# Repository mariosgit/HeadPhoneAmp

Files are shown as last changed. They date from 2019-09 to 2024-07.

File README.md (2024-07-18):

# HeadPhoneAmp

New plan... Make my own HP Amp.

##### Requirements:

* EQ - I dont have many HP's which I don't want to EQ, they all need a little something.
* Lipo Powered !
* Line In

##### Goodies

* More Inputs (in that order)
   * USB (Teensy4 can also control DSP, Bluetooth, 16bit is ok for playback)
   * BT (just plug in a module CSR8635?)
   * WLAN (Radio, Subsonic and Ampache protocols for nextcloud music) cry for ESP32 (rabbithole! [bt a2dp](https://github.com/pschatzmann/ESP32-A2DP) [iradio](https://github.com/Edzelf/ESP32Radio-V2) [streem gedoehns](https://github.com/sle118/squeezelite-esp32) )
   * SPDIF (not really on a HP amp)
* Second output ? With it's own EQ and Volume ?
* NuTube or Simulation of a little distortion. Maybe other effects ?
* MP3 player - there is one for the teensy. Would need SDCard or so, How to copy files ? Just swap the card ? The Cardhold would obscure the VUSB hack !
* ~~Radio streaming.. WLAN hasl...~~

# Status

* Theory is somewhat more defined in my head.
* Started to build some blocks
    * TPA6120 module - Made my own, running with only single 5V - to be tested.
    * DSP - I have a freeDSP-SMD-B to experiment with
    * NuTube ? I have a NuTube HP Amp which is'nt great but could be recycled into something usefull - not so available !

# Next up ?

#### HPAmp design ?

* TPA6120A2 in the works with 5V conveter, it's big (there is a QFN version)

#### Power Block Design

* Use Adafruit PowerThing ?
    * Added charge pump for 10V as in the DS
* How to get the teensy integrated, would need to patch into VUSB -> PowerBlock -> 5V back to the Teensy ?
    * Cut trace in the back, solder some wire to VUSB ? Or use pogopins ? Not nice.
* Noise ??? Will see... yes 200mVpp @ 65kHz, audible when directly driving a 16ohm speaker

* Cap Mult for analog voltage, or just a regulator ? [SIM](https://www.falstad.com/circuit/circuitjs.html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)

##### Results v0.1

* C6 can be much larger according to DS. Available up to 220uF.
* Has no BAT protection ? The testbat emptied down to 2V ! Just clarify.
* Make charge Amps quick changeable with a PHT resistor ?
* Could add a PG PowerGood LED, this shows when device is connected to some power source
* Check 10V load ❗
* Add option for higher voltage as in the GP??94 controller ?

##### Bugs v0.1

* ! Q1 is **wrong** MMUN2133LT1G it's BEC(123) - just switched to the "BEC" symbol. ✅
* C5 (+10V) was connected to ground, should be between +10 and +5V, works anyway ✅

#### NuTube

* Create own board 
    * Bias voltage driven by OpAmp ! Input a single Pot or CV
    * With ADC ? as a FX loopback ?

#### VFD/OLED

* Make board for MN12832 ?
    * Can I borrow voltage from the booster ? Add more charge pumps..

#### Teensy + DSP

* Can the teensy be slave i2s ??? Otherwise it would need an extra SRC.
    There is a slave i2s out... Will it work with usb, does it need to be 44100kHz ?
    ```
    AudioInputUSB            usb1;
    AudioOutputI2Sslave      i2sslave1;
    AudioConnection          patchCord1(usb1, 0, i2sslave1, 0);
    AudioConnection          patchCord2(usb1, 1, i2sslave1, 1);
    ```
    ```File > Examples > Audio > HardwareTesting > WM8731MikroSine```
    *Notes: Slave mode I2S should not used in the same project as ADC, DAC and PWM signals. Differences in timing between the I2S device and Teensy's clock can cause occasional audio glitches when I2S slave mode is used together with other input or output objects based on Teensy's timing. ...Only one I2S input and one I2S output object may be used. Master and slave modes may not be mixed (both must be of the same type).*
    Mhm wanted to use the internal DAC for NuTube bias...
* Test I2S slave (with DSP)
* Test internal DAC for NuTube

#### BT Audio

* Ahh just another SRC needed ??? Or switch them between Teensy and BT ? And SPDif ?
* Make a SPDIF/BT/USB I2S Switch + SRC  block design. it's all there.

##### Advanced 

* Loop back Nutube ? With an extra ADC or CODEC ? Ad

# Log

| What | Time | Cost || What | Time | Cost |
|---|---|---|---|---|---|---|
| Make Power PCB | 1d | | | Test,Fix Power PCB | 1d | |
|  Make HPBooster PCB | 1d | | | | | |
| both mat+pcb | | 50 + 30 | | |

# Refs

Used some Symbols... https://github.com/wykys/klib 

Ti's [I2C expander collection](https://www.ti.com/interface/i2c/general-purpose-ios-gpios/overview.html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)

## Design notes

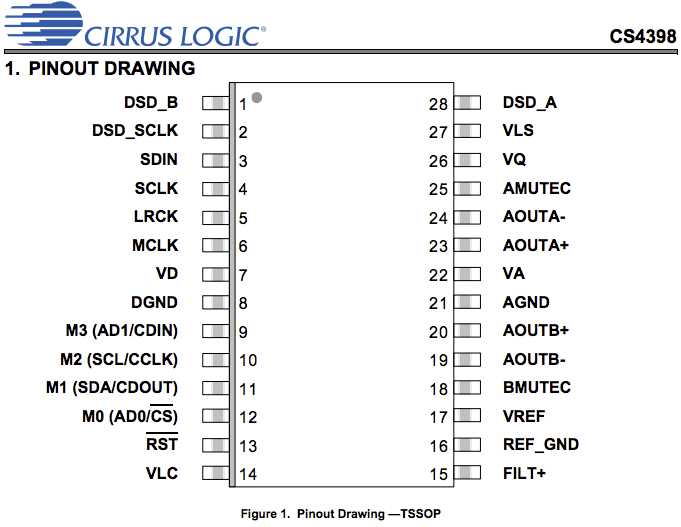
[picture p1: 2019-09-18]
images/CS4398pinout.png

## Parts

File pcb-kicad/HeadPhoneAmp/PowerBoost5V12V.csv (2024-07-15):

Reference | Value | Footprint | Qty | # | MFNAME
B1,CHRG/LBO0,DONE0,JP2,LED1,LED2,TP1,TP2,TP3,TP4,TP5 | ~ | -- mixed values -- | 11 | 1
C1,C2,C5,C7,C8 | 2.2u | Capacitor_SMD:C_0603_1608Metric_Pad1.08x0.95mm_HandSolder | 5 | 2 | EMK107BJ225KA-T
C3,C4 | 100n | Capacitor_SMD:C_0603_1608Metric_Pad1.08x0.95mm_HandSolder | 2 | 3 | C0603C104M4RAC7411
C6 | 22u | Capacitor_SMD:C_1210_3225Metric_Pad1.33x2.70mm_HandSolder | 1 | 4 | 293D226X96R3A2TE3
D1 | BAT54S | Package_TO_SOT_SMD:SOT-23 | 1 | 5 | BAT54S
L1 | 6.8uH 2A | Adafruit PowerBoost 1000C Rev B:INDUCTOR_5X5MM_TDK_VLC5045 | 1 | 6 | 74406042068
Q1 | Q_PNP_ECB_BRT | Package_TO_SOT_SMD:SOT-23 | 1 | 7 | MMUN2133LT1G
R1,R3 | 1.87M | Resistor_SMD:R_0603_1608Metric_Pad0.98x0.95mm_HandSolder | 2 | 8 | RK73H1HTTCM4302D RK73H1JTTD1874F
R2 | 340k | Resistor_SMD:R_0603_1608Metric_Pad0.98x0.95mm_HandSolder | 1 | 9 | RK73H1JTTD3403F
R4,R7,R9,R13,R17 | 100k | Resistor_SMD:R_0603_1608Metric_Pad0.98x0.95mm_HandSolder | 5 | 10 | RK73H1JTTD1003F
R5,R8,R14,R16,R20 | 1k | Resistor_SMD:R_0603_1608Metric_Pad0.98x0.95mm_HandSolder | 5 | 11 | RK73H1JTTD1001F
R6 | 270k | Resistor_SMD:R_0603_1608Metric_Pad0.98x0.95mm_HandSolder | 1 | 12 | RK73H1JTTD2703F
THERM0 | 15k | Resistor_SMD:R_0603_1608Metric_Pad0.98x0.95mm_HandSolder | 1 | 13 | RK73H1JTTD1502F
U1 | VREG_TPS6103X | HPAmp:PVQFN-16 | 1 | 14 | TPS61090RSAR
U2 | MCP73871 | HPAmp:QFN20_4MM | 1 | 15 | MCP73871T

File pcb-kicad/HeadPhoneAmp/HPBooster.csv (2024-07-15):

Reference | Value | Qty | MFNAME
C1,C4,C5,C6,C7 | 10u | 5 | -
C2,C3,C8,C9,C42,C43 | 100n | 6 | -
FB1,FB2,FB3 | FerriteBead | 3 | -
J1,J2,J3,TP1,TP2,TP3,TP5+1,TP5-1 | ~ | 8 | -
L1 | 2.2uH | 1 | CC453232-2R2KL
R1 | 365k | 1 | RK73H1JTTD3653F
R2,R3 | 47 | 2 | RK73H1JTTD47R0F
R4,R5 | 39.2 | 2 | RK73H3ATTE39R2F
R6 | 120k | 1 | RK73H1JTTD1203F
R7 | 487k | 1 | RK73H1JTTD4873F
R36,R37,R38,R39 | 1k | 4 | -
U1 | TPS65135 | 1 | -
U5 | TPA6120A2RGY | 1 | -

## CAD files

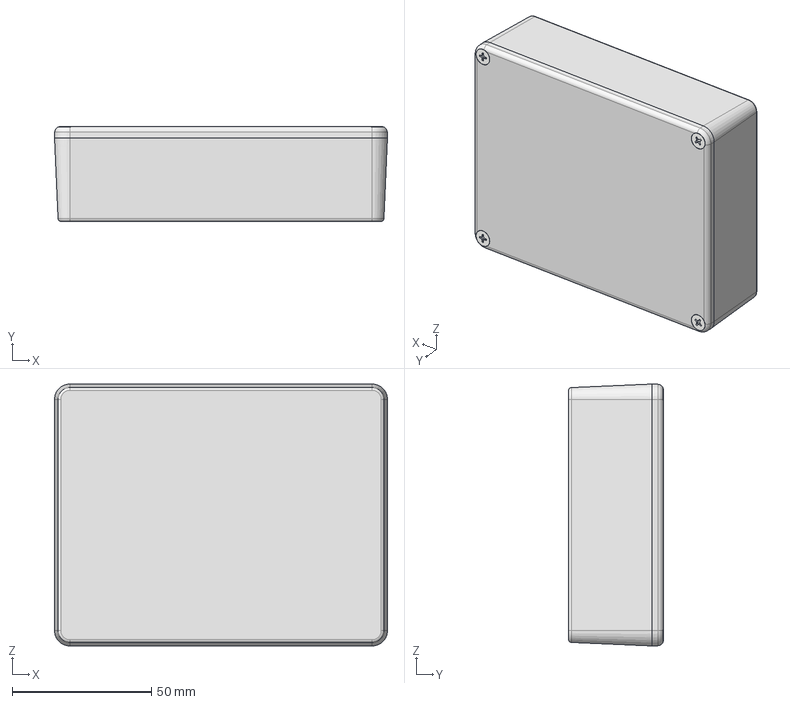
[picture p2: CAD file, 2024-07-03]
pcb-kicad/3dModels/Case1590BB.stp
119.5 x 34.0 x 94.0 mm

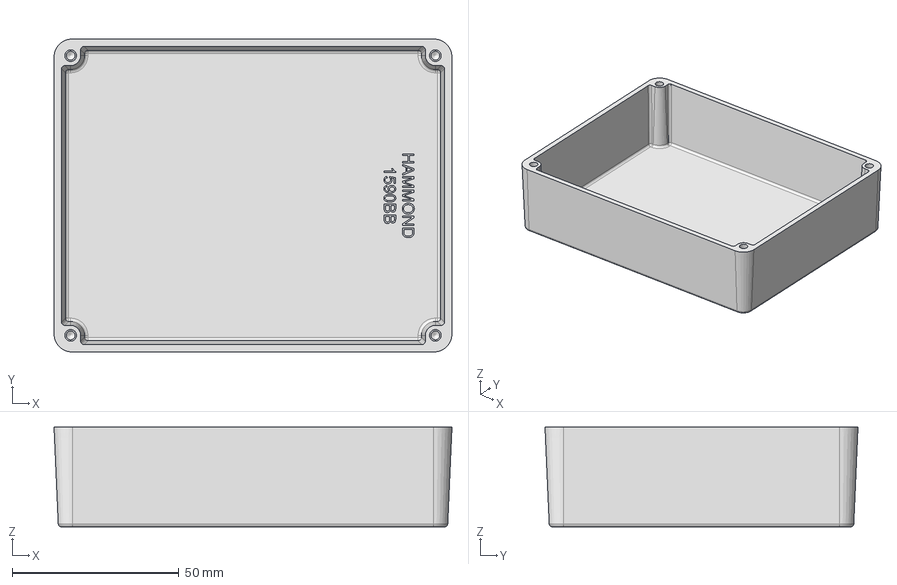
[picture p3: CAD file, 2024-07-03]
pcb-kicad/3dModels/Case1590BB-TOP.step
119.5 x 94.0 x 30.0 mm

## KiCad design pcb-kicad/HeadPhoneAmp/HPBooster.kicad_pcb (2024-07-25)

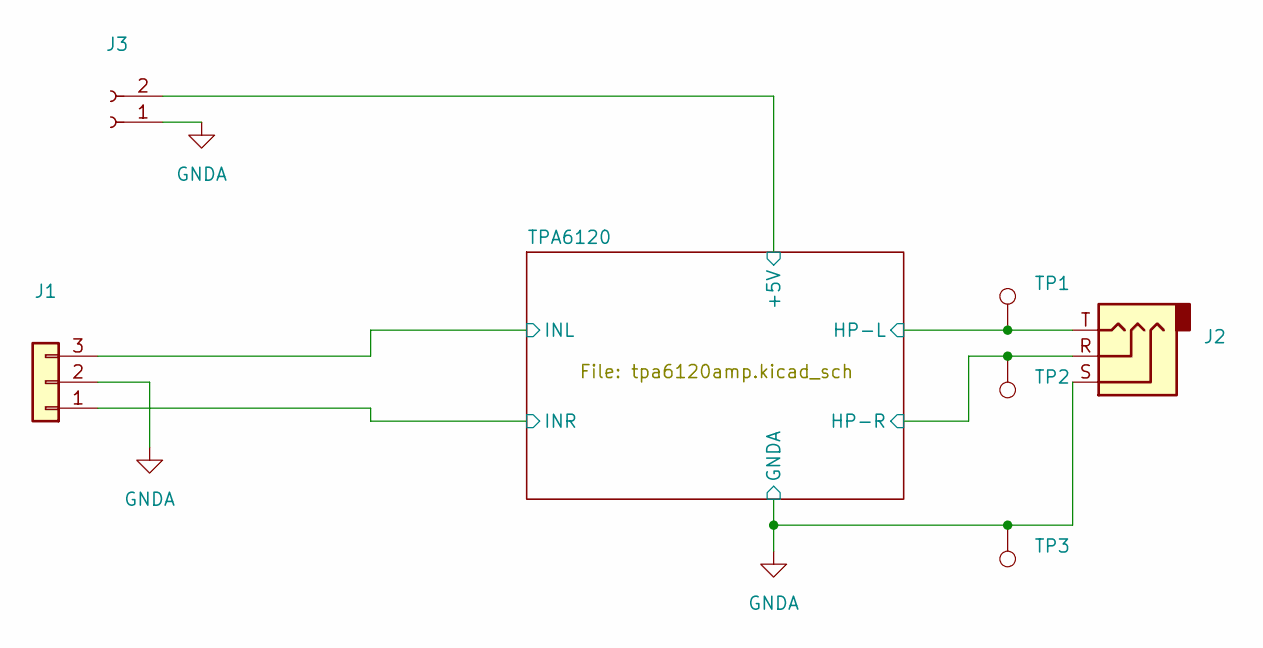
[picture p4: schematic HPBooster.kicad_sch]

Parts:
J1: JST_EH_B3B-EH-A_1x03_P2.50mm_Vertical
J2: Jack_3.5mm_CUI_SJ-3523-SMT_Horizontal
J3: PinHeader_1x02_P2.54mm_Vertical
TP1, TP2, TP3: TestPoint_Loop_D1.80mm_Drill1.0mm_Beaded

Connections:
+5V: J3.2; also elsewhere on the board
/TPA6120/HP-L: J2.T, TP1.1; also elsewhere on the board
/TPA6120/HP-R: J2.R, TP2.1; also elsewhere on the board
/TPA6120/INL: J1.3; also elsewhere on the board
/TPA6120/INR: J1.1; also elsewhere on the board
GNDA: J1.2, J2.S, J3.1, TP3.1; also elsewhere on the board

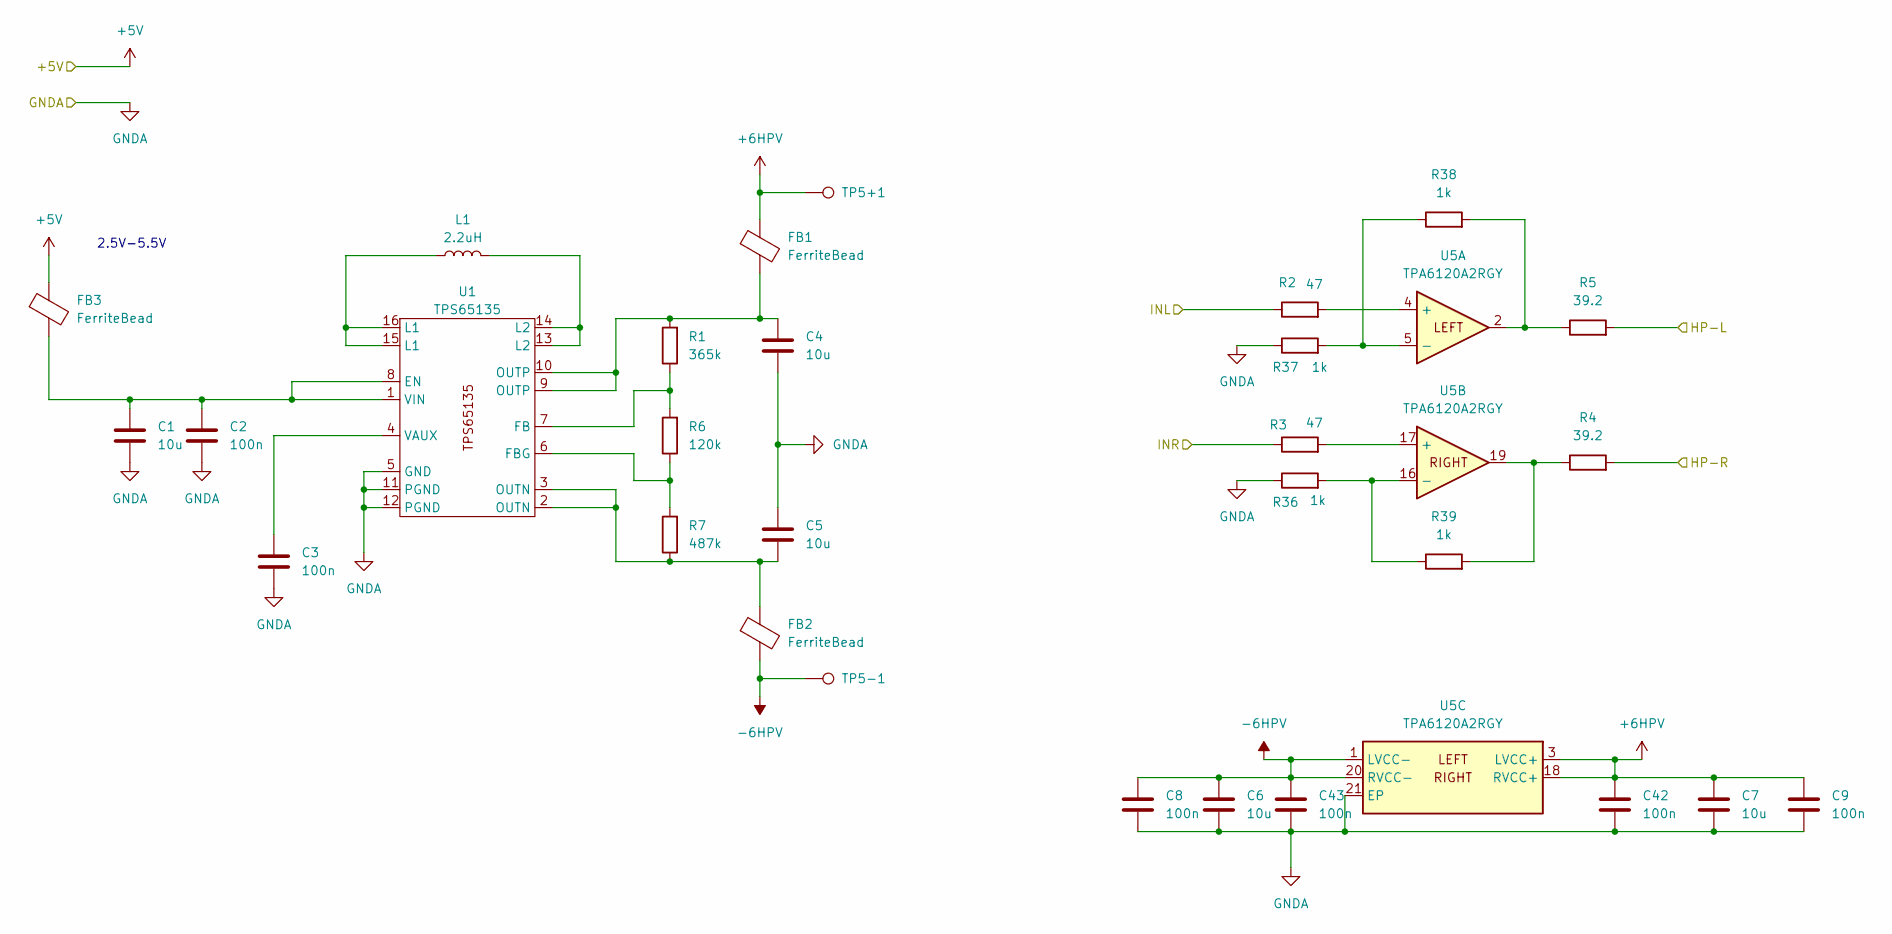
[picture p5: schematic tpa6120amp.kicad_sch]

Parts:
C1, C4, C5, C6, C7: 10u; C_0603_1608Metric_Pad1.08x0.95mm_HandSolder
C2, C3, C8, C9, C42, C43: 100n; C_0603_1608Metric_Pad1.08x0.95mm_HandSolder
FB1, FB2, FB3: FerriteBead; L_0603_1608Metric_Pad1.05x0.95mm_HandSolder
L1: 2.2uH; L_1812_4532Metric_Pad1.30x3.40mm_HandSolder
R1: 365k; R_0603_1608Metric_Pad0.98x0.95mm_HandSolder
R2, R3: 47; R_0603_1608Metric_Pad0.98x0.95mm_HandSolder
R4, R5: 39.2; R_2512_6332Metric_Pad1.40x3.35mm_HandSolder
R6: 120k; R_0603_1608Metric_Pad0.98x0.95mm_HandSolder
R7: 487k; R_0603_1608Metric_Pad0.98x0.95mm_HandSolder
R36, R37, R38, R39: 1k; R_0603_1608Metric_Pad0.98x0.95mm_HandSolder
TP5+1, TP5-1: TestPoint_Pad_2.0x2.0mm
U1: TPS65135; WQFN-16-1EP_3x3mm_P0.5mm_LongPad_ThermalVia
U5: TPA6120A2RGY; SOP-20_7.5x12.8mm_P1.27mm

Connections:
+5V: FB3.1; also elsewhere on the board
+6HPV: C7.1, C9.1, C42.1, FB1.1, TP5+1.1, U5.3 (LVCC+), U5.18 (RVCC+)
-6HPV: C6.1, C8.1, C43.1, FB2.2, TP5-1.1, U5.1 (LVCC-), U5.20 (RVCC-)
/TPA6120/HP-L: R5.2; also elsewhere on the board
/TPA6120/HP-R: R4.2; also elsewhere on the board
/TPA6120/INL: R2.1; also elsewhere on the board
/TPA6120/INR: R3.1; also elsewhere on the board
GNDA: C1.2, C2.2, C3.2, C4.2, C5.1, C6.2, C7.2, C8.2, C9.2, C42.2, C43.2, R36.1, R37.1, U1.5 (GND), U1.11 (PGND), U1.12 (PGND), U5.21 (EP); also elsewhere on the board
unnamed: C4.1, FB1.2, R1.2, U1.9 (OUTP), U1.10 (OUTP)
unnamed: C5.2, FB2.1, R7.1, U1.2 (OUTN), U1.3 (OUTN)
unnamed: L1.1, U1.15 (L1), U1.16 (L1)
unnamed: L1.2, U1.13 (L2), U1.14 (L2)
unnamed: R5.1, R38.2, U5.2
unnamed: R4.1, R39.2, U5.19
unnamed: C1.1, C2.1, FB3.2, U1.1 (VIN), U1.8 (EN)
unnamed: R1.1, R6.2, U1.7 (FB)
unnamed: R6.1, R7.2, U1.6 (FBG)
unnamed: C3.1, U1.4 (VAUX)
unnamed: R2.2, U5.4 (+)
unnamed: R37.2, R38.1, U5.5 (-)
unnamed: R3.2, U5.17 (+)
unnamed: R36.2, R39.1, U5.16 (-)

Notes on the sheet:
2.5V-5.5V

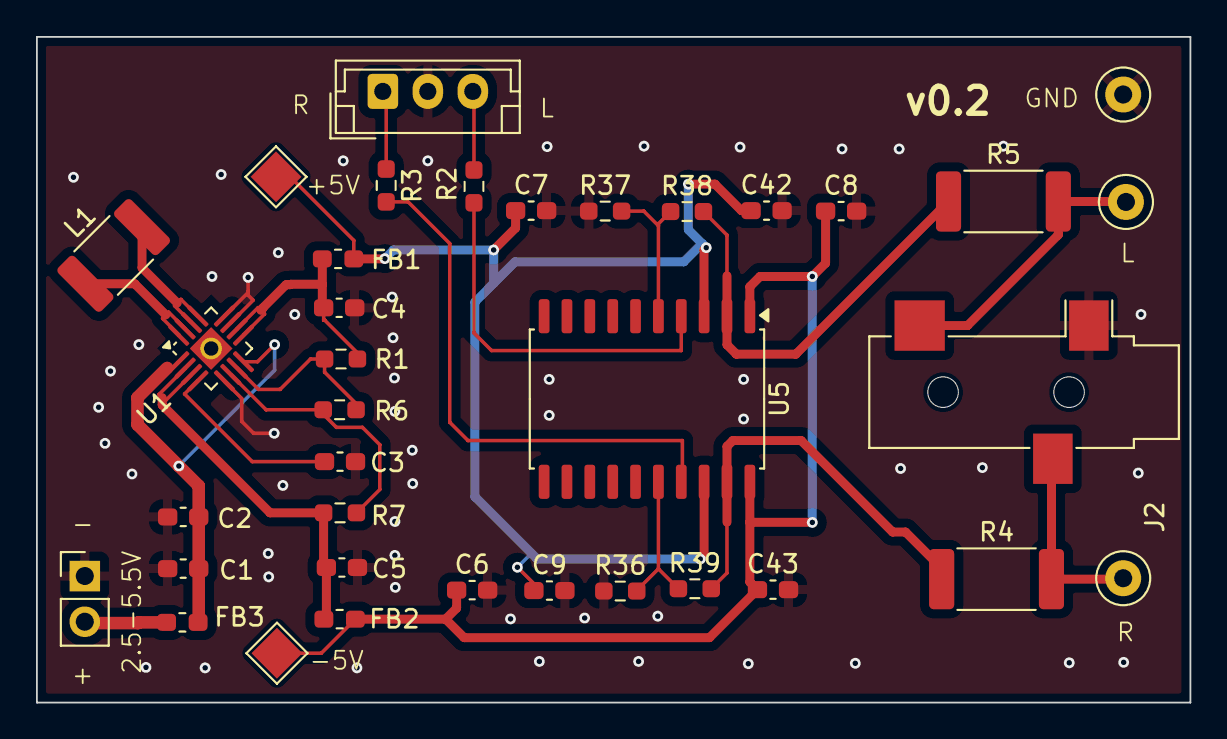
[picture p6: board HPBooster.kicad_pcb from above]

Board: 2 copper layers, 64.1 x 37.0 mm, 36 parts (0 on the bottom side), 22 nets.

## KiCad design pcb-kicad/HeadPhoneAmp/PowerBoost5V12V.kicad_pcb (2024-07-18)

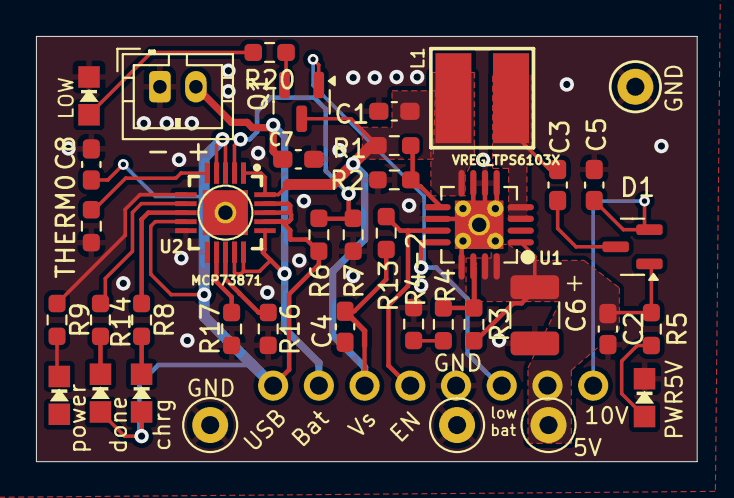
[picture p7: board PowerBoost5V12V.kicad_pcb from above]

Board: 2 copper layers, 36.7 x 23.6 mm, 41 parts (0 on the bottom side), 26 nets.

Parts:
B1: JST_PH_B2B-PH-K_1x02_P2.00mm_Vertical
C1, C2, C5, C7, C8: 2.2u; C_0603_1608Metric_Pad1.08x0.95mm_HandSolder
C3, C4: 100n; C_0603_1608Metric_Pad1.08x0.95mm_HandSolder
C6: 22u; C_1210_3225Metric_Pad1.33x2.70mm_HandSolder
CHRG/LBO0: CHIPLED_0805_NOOUTLINE
D1: BAT54S; SOT-23
DONE0: CHIPLED_0805_NOOUTLINE
JP2: 1X08_ROUND
L1: 6.8uH 2A; INDUCTOR_5X5MM_TDK_VLC5045
LED1, LED2: CHIPLED_0805_NOOUTLINE
LEDPG1: PG; CHIPLED_0805_NOOUTLINE
Q1: Q_PNP_BEC_BRT; SOT-23
R1, R3: 1.87M; R_0603_1608Metric_Pad0.98x0.95mm_HandSolder
R2: 340k; R_0603_1608Metric_Pad0.98x0.95mm_HandSolder
R4, R4-2, R7, R13, R17: 100k; R_0603_1608Metric_Pad0.98x0.95mm_HandSolder
R5, R8, R9, R14, R16, R20: 1k; R_0603_1608Metric_Pad0.98x0.95mm_HandSolder
R6: 270k; R_0603_1608Metric_Pad0.98x0.95mm_HandSolder
THERM0: 15k; R_0603_1608Metric_Pad0.98x0.95mm_HandSolder
TP1: TestPoint_Keystone_5000-5004_Miniature
TP2, TP3, TP4, TP5: TestPoint_Loop_D1.80mm_Drill1.0mm_Beaded
U1: VREG_TPS6103X; PVQFN-16
U2: MCP73871; QFN20_4MM

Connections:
5.0V: C2.1, C6.1, D1.1 (A), JP2.7, R3.2, R5.1, TP2.1, U1.1 (VOUT), U1.15 (VOUT), U1.16 (VOUT)
+10V: C5.1, D1.2 (K), JP2.8
/ENABLE: JP2.4, R13.2, U1.11 (EN)
/LBO: JP2.6, Q1.1 (B), U1.12 (LBO)
GND: B1.1 (-), C1.2, C2.2, C4.2, C5.2, C6.2, C7.2, C8.2, JP2.5, LED1.C, LED2.C, R2.1, R4-2.1, R7.2, R16.1, R17.1, THERM0.1, TP1.1, TP3.1, TP4.1, TP5.1, U1.5 (PGND), U1.6 (PGND), U1.7 (PGND), U1.10 (SYNC), U1.13 (GND), U1.P$18 (PGND), U1.P$19 (PGND), U1.P$20 (PGND), U1.P$21 (PGND), U1.P$22 (PGND), U1.THERMAL (PGND), U2.P$10 (VSS1), U2.P$11 (VSS2), U2.P$21 (THERMAL)
unnamed: CHRG/LBO0.C, R8.2
unnamed: C3.1, D1.3 (COM)
unnamed: DONE0.C, R14.2
unnamed: C3.2, L1.P$2 (2), U1.3 (SW), U1.4 (SW)
unnamed: LED1.A, R20.1
unnamed: LED2.A, R5.2
unnamed: LEDPG1.C, R9.2
unnamed: Q1.2 (E), R20.2
unnamed: R4.1, R4-2.2
unnamed: R3.1, R4.2, U1.14 (FB)
unnamed: R1.1, R2.2, U1.9 (LBI)
unnamed: R16.2, U2.P$13 (PROG1)
unnamed: R17.2, U2.P$12 (PROG3)
unnamed: R8.1, U2.P$8 (STAT1/LBO)
unnamed: R14.1, U2.P$7 (STAT2)
unnamed: THERM0.2, U2.P$5 (THERM)
unnamed: R6.1, R7.1, U2.P$2 (VPCC)
unnamed: R9.1, U2.P$6 (/PG)
VBAT: C1.1, C4.1, JP2.3, L1.P$1 (1), Q1.3 (C), R1.2, R13.1, U1.8 (VBAT), U2.P$1 (VOUT1), U2.P$20 (VOUT2)
VBUS: C8.1, CHRG/LBO0.A, DONE0.A, JP2.1, LEDPG1.A, R6.2, U2.P$3 (SEL), U2.P$4 (PROG2), U2.P$9 (/TE), U2.P$17 (CE), U2.P$18 (VIN1), U2.P$19 (VIN2)
VLIPO: B1.2 (+), C7.1, JP2.2, U2.P$14 (VBAT1), U2.P$15 (VBAT2), U2.P$16 (VBATSENS)

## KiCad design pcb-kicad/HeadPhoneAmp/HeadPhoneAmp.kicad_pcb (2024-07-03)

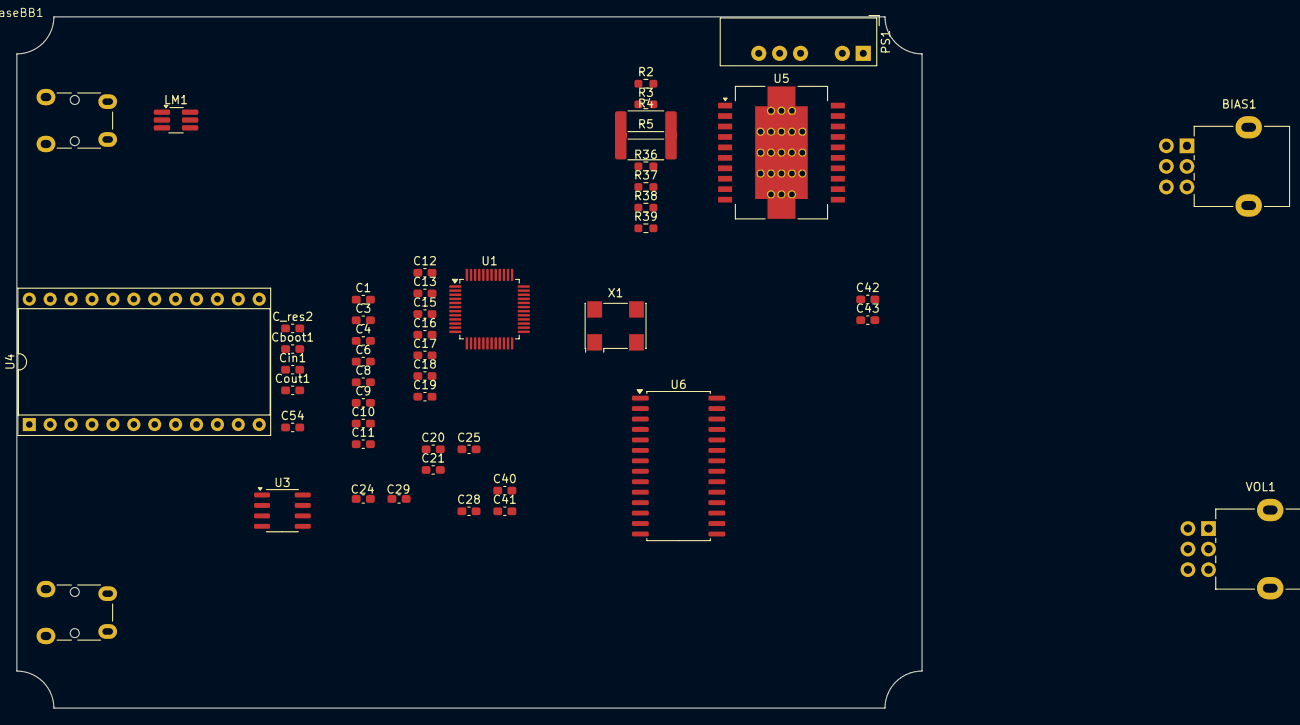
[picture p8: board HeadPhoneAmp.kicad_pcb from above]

Board: 2 copper layers, 110.0 x 84.0 mm, 51 parts (0 on the bottom side), 33 nets, no tracks yet.

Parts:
BIAS1: R_Potentiometer_Dual; Potentiometer_Alpha_RD902F-40-00D_Dual_Vertical
C1, C3, C4, C6, C8, C9, C10, C11, C13, C16, C17, C40, C41, C42, C43: 100n; C_0603_1608Metric_Pad1.08x0.95mm_HandSolder
C12, C15, C54: 10u; C_0603_1608Metric_Pad1.08x0.95mm_HandSolder
C18: 3n3; C_0603_1608Metric_Pad1.08x0.95mm_HandSolder
C19: 56n; C_0603_1608Metric_Pad1.08x0.95mm_HandSolder
C20, C21: 100p; C_0603_1608Metric_Pad1.08x0.95mm_HandSolder
C24, C25: 330p; C_0603_1608Metric_Pad1.08x0.95mm_HandSolder
C28, C29: 5.6n; C_0603_1608Metric_Pad1.08x0.95mm_HandSolder
C_res2: x; C_0603_1608Metric_Pad1.08x0.95mm_HandSolder
CaseBB1: CaseBB
Cboot1: 220n; C_0603_1608Metric_Pad1.08x0.95mm_HandSolder
Cin1: 2u2; C_0603_1608Metric_Pad1.08x0.95mm_HandSolder
Cout1: 47u; C_0603_1608Metric_Pad1.08x0.95mm_HandSolder
J4, J5: AudioJack3; Jack_3.5mm_Lumberg_1503_07_Horizontal
LM1: LM284x; TSOT-23-6_HandSoldering
PS1: IA0509S; Converter_DCDC_XP_POWER-IAxxxxS_THT
R2, R3: 47; R_0603_1608Metric_Pad0.98x0.95mm_HandSolder
R4, R5: 39.2; R_2512_6332Metric_Pad1.40x3.35mm_HandSolder
R36, R37, R38, R39: 1k; R_0603_1608Metric_Pad0.98x0.95mm_HandSolder
U1: ADAU1701; LQFP-48_7x7mm_P0.5mm
U3: LME49721; SOIC-8_3.9x4.9mm_P1.27mm
U4: DIP-24_W15.24mm_Socket
U5: TPA6120A2RGY; HSOP-20-1EP_11.0x15.9mm_P1.27mm_SlugDown_ThermalVias
U6: PGA4311; SOIC-28W_7.5x17.9mm_P1.27mm
VOL1: R_Potentiometer_Dual; Potentiometer_Alpha_RD902F-40-00D_Dual_Vertical
X1: ASV-24.576MHz-EJ-T; Oscillator_SMD_Abracon_ASV-4Pin_7.0x5.1mm

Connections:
+3V3: C6.2, C8.2, C9.2, C10.2, C11.2, C18.1, C40.1, C41.1, C_res2.1, Cout1.1, U1.6 (SELFBOOT), U1.18 (IOVDD), U1.34 (PVDD), U1.36 (AVDD), U1.38 (PLL_MODE0), U1.39 (PLL_MODE1), U1.48 (AVDD), U3.8 (V+)
+9V: C42.1, PS1.6 (+Vout), U5.3 (LVCC+), U5.18 (RVCC+)
-9V: C43.1, PS1.4 (-Vout), U5.1 (LVCC-), U5.20 (RVCC-)
/HP-AMP/HP-L: J4.T, R5.2
/HP-AMP/HP-R: J4.R, R4.2
/HP-AMP/INL: R2.1, U6.5 (Aout_1)
/HP-AMP/INR: R3.1, U6.24 (Aout_2)
ADC0: J5.R, U1.2 (ADC0)
ADC1: J5.T, U1.4 (ADC1)
BRD_RST: C1.1, U1.5 (~RESET)
GND: C1.2, C3.1, C4.1, C6.1, C8.1, C9.1, C10.1, C11.1, C12.1, C13.2, C15.1, C16.2, C17.2, C20.2, C21.2, C28.2, C29.2, C40.2, C41.2, C54.2, C_res2.2, Cin1.2, Cout1.2, LM1.2 (GND), U1.1 (AGND), U1.7 (ADDR0), U1.12 (DGND), U1.25 (DGND), U1.30 (RSVD), U1.33 (PGND), U1.37 (AGND), U1.42 (AGND), U3.4 (V-), X1.2 (GND)
GNDA: C42.2, C43.2, J4.S, J5.S, PS1.5 (0V), R36.1, R37.1, U5.21 (EP), U6.2 (AGND_1), U6.4 (AGND_1), U6.9 (AGND_3), U6.11 (AGND_3), U6.18 (AGND_4), U6.20 (AGND_4), U6.25 (AGND_2), U6.27 (AGND_2)
unnamed: Cboot1.1, LM1.6 (SW)
unnamed: Cboot1.2, LM1.1 (CB)
unnamed: Cin1.1, LM1.4 (SHDN), LM1.5 (Vin)
unnamed: C3.2, C4.2, U1.13 (DVDD), U1.24 (DVDD)
unnamed: R5.1, R38.2, U5.2
unnamed: R4.1, R39.2, U5.19
unnamed: C16.1, U1.40 (CM)
unnamed: C12.2, C13.1, U1.47 (FILTA)
unnamed: C15.2, C17.1, U1.41 (FILTD)
unnamed: C18.2, C19.2, U1.35 (PLL_LF)
unnamed: C20.1, U3.3 (+)
unnamed: C24.1, U3.1, U3.2 (-)
unnamed: C21.1, U3.5 (+)
unnamed: C25.1, U3.6 (-), U3.7
unnamed: R2.2, U5.4 (+)
unnamed: R37.2, R38.1, U5.5 (-)
unnamed: R3.2, U5.17 (+)
unnamed: R36.2, R39.1, U5.16 (-)
unnamed: U6.7 (VA+), U6.22 (VA+)
unnamed: U6.6 (VA-), U6.23 (VA-)
unnamed: C54.1, X1.1 (Control), X1.4 (Vcc)

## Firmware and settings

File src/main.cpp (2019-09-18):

#include <Arduino.h>
#include <TM1637Display.h>
#include <TinyWireM.h>

// I2C:
// TinyWireM: https://github.com/adafruit/TinyWireM

// 7 Segment LED Module connection pins (Digital Pins)
#define CLK 2
#define DIO 3

#define pinVolume A0
// #define PORT_USI_SDA	PA6
// #define PORT_USI_SCL	PA4

// The amount of time (in milliseconds) between tests
#define TEST_DELAY 2000

const uint8_t SEG_DONE[] = {
    SEG_B | SEG_C | SEG_D | SEG_E | SEG_G,         // d
    SEG_A | SEG_B | SEG_C | SEG_D | SEG_E | SEG_F, // O
    SEG_C | SEG_E | SEG_G,                         // n
    SEG_A | SEG_D | SEG_E | SEG_F | SEG_G          // E
};

TM1637Display display(CLK, DIO);

void setup()
{
    TinyWireM.begin();
    /*
        TinyWireM.beginTransmission(DS1621_ADDR);
        TinyWireM.send(0xAC);                 // Access Command Register
        TinyWireM.send(B00000001);            // Using one-shot mode for battery savings
        //TinyWireM.send(B00000000);          // if setting continious mode for fast reads
        TinyWireM.endTransmission();          // Send to the slave

        CS4398 Test mit Mute on/off
        Mute Register = 0x04
        default = B11000000 = 0xC0
        muted =   B11011000 = 0xd8

        Chip Adr = B[rw]1001111 ( The upper five bits of the 7-bit address field must be 10011. The lower 2 bits are AD1,AD0 pins )
        write = adr + regadr + data
                10011xx + 0x04 + 0xd8
                xx are what the AD[10] pins are set to. (1!)

    */
    // this should mute it
    TinyWireM.beginTransmission(B01001111);
    TinyWireM.send(0x04);
    TinyWireM.send(B11011000);
    TinyWireM.endTransmission();
}

void loop()
{
    // example for volume control
    while(1)
    {
        // CS4398 volume: 0=0dB, 1=-.5dB, 255=-127.5 dB
        int aval = analogRead(pinVolume) - 1023;
        display.showNumberDec(aval / 8, false); // Expect: ___0
        delay(20);
    }

    int k;
    uint8_t data[] = {0xff, 0xff, 0xff, 0xff};
    display.setBrightness(0x0f);

    // All segments on
    display.setSegments(data);
    delay(TEST_DELAY);

    // Selectively set different digits
    data[0] = display.encodeDigit(0);
    data[1] = display.encodeDigit(1);
    data[2] = display.encodeDigit(2);
    data[3] = display.encodeDigit(3);
    display.setSegments(data);
    delay(TEST_DELAY);

    /*
  for(k = 3; k >= 0; k--) {
	display.setSegments(data, 1, k);
	delay(TEST_DELAY);
	}
  */

    display.clear();
    display.setSegments(data + 2, 2, 2);
    delay(TEST_DELAY);

    display.clear();
    display.setSegments(data + 2, 2, 1);
    delay(TEST_DELAY);

    display.clear();
    display.setSegments(data + 1, 3, 1);
    delay(TEST_DELAY);

    // Show decimal numbers with/without leading zeros
    display.showNumberDec(0, false); // Expect: ___0
    delay(TEST_DELAY);
    display.showNumberDec(0, true); // Expect: 0000
    delay(TEST_DELAY);
    display.showNumberDec(1, false); // Expect: ___1
    delay(TEST_DELAY);
    display.showNumberDec(1, true); // Expect: 0001
    delay(TEST_DELAY);
    display.showNumberDec(301, false); // Expect: _301
    delay(TEST_DELAY);
    display.showNumberDec(301, true); // Expect: 0301
    delay(TEST_DELAY);
    display.clear();
    display.showNumberDec(14, false, 2, 1); // Expect: _14_
    delay(TEST_DELAY);
    display.clear();
    display.showNumberDec(4, true, 2, 2); // Expect: __04
    delay(TEST_DELAY);
    display.showNumberDec(-1, false); // Expect: __-1
    delay(TEST_DELAY);
    display.showNumberDec(-12); // Expect: _-12
    delay(TEST_DELAY);
    display.showNumberDec(-999); // Expect: -999
    delay(TEST_DELAY);
    display.clear();
    display.showNumberDec(-5, false, 3, 0); // Expect: _-5_
    delay(TEST_DELAY);
    display.showNumberHexEx(0xf1af); // Expect: f1Af
    delay(TEST_DELAY);
    display.showNumberHexEx(0x2c); // Expect: __2C
    delay(TEST_DELAY);
    display.showNumberHexEx(0xd1, 0, true); // Expect: 00d1
    delay(TEST_DELAY);
    display.clear();
    display.showNumberHexEx(0xd1, 0, true, 2); // Expect: d1__
    delay(TEST_DELAY);

    // Run through all the dots
    for (k = 0; k <= 4; k++)
    {
        display.showNumberDecEx(0, (0x80 >> k), true);
        delay(TEST_DELAY);
    }

    // Brightness Test
    for (k = 0; k < 4; k++)
        data[k] = 0xff;
    for (k = 0; k < 7; k++)
    {
        display.setBrightness(k);
        display.setSegments(data);
        delay(TEST_DELAY);
    }

    // On/Off test
    for (k = 0; k < 4; k++)
    {
        display.setBrightness(7, false); // Turn off
        display.setSegments(data);
        delay(TEST_DELAY);
        display.setBrightness(7, true); // Turn on
        display.setSegments(data);
        delay(TEST_DELAY);
    }

    // Done!
    display.setSegments(SEG_DONE);

    //   while(1);
}

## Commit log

2019-09-18 At least tested the display and volume pot on an Arduino
2024-07-09 Added TPA6120 breakout.
    [Adafruit PowerBoost 1000C Rev B.kicad_pcb, Adafruit PowerBoost 1000C Rev B.kicad_sch, HPBooster.kicad_pcb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]
2024-07-11 Added Bat Charger ala PowerBoost.
    [Adafruit PowerBoost 1000C Rev B.kicad_pcb, Adafruit PowerBoost 1000C Rev B.kicad_sch, PowerBoost5V12V.kicad_pcb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]
2024-07-15 Added some order infos.
    [HPBooster.csv, HPBooster.kicad_pcb, HPBooster.kicad_sch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]
2024-07-16 Mini fixes
    [PowerBoost5V12V.kicad_sch]
2024-07-18 Fixed PowerBlock PCB it's v0.2 now
    [PowerBoost5V12V.kicad_pcb, PowerBoost5V12V.kicad_sch]
2024-07-25 HPBooster v0.2, changed TPA footprint.
    [HPBooster.kicad_pcb, tpa6120amp.kicad_sch]
